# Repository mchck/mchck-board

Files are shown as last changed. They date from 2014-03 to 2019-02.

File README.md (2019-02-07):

The MC HCK!
===========

The goal is to have a small, cheap, and powerful development board
that supports USB for easy programming, at a low price (current
estimate: $7, target $5). This allows us to use the board for all
silly purposes where spending >$20 for other microcontroller boards is
just too much.

The schematic design and layout was done using KiCad <http://kicad.sourceforge.net>,
a Free Software EDA tool for Linux, Windows and Mac OS.  You will need
KiCad to open the .sch or .brd files - gEDA or Eagle will not work.

Copyright
---------

Copyright (c) 2011,2012 Simon Schubert <2@0x2c.org>

This documentation describes Open Hardware and is licensed under the
CERN OHL v. 1.1.  You may redistribute and modify this documentation
under the terms of the CERN OHL v.1.1.  You can find a copy of the
CERN OHL v.1.1 in the file <LICENSE>.

Fabrication outputs
-------------------

If you got this from the git repository, you should be able to find
fabrication outputs in the "fab" branch.  This branch gets updated by
running `make ci-fab`.

Contact
-------

Simon Schubert <2@0x2c.org>

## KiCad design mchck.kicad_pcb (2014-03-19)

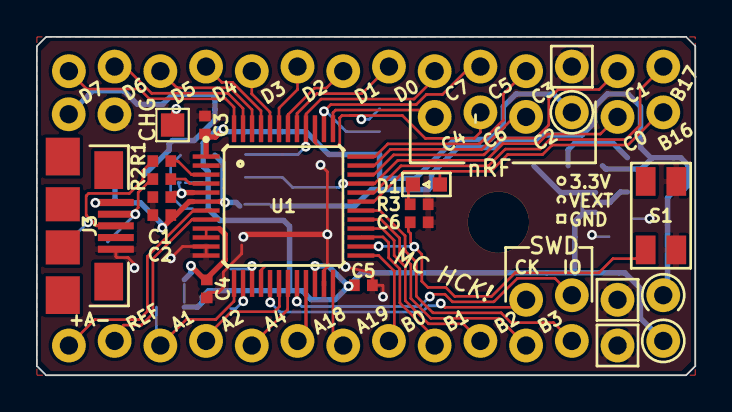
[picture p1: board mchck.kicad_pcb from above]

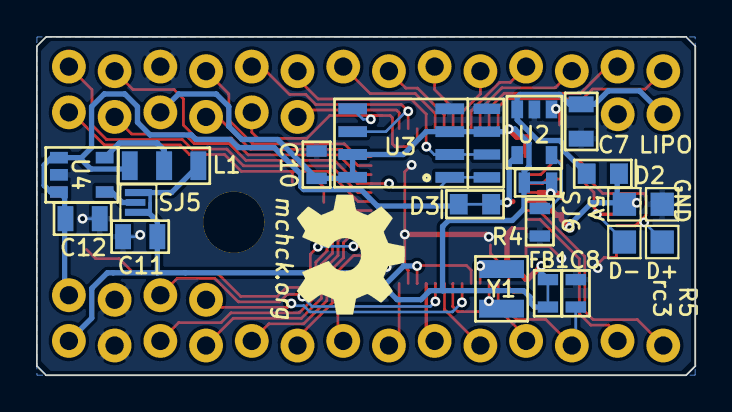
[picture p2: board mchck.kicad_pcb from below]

Board: 2 copper layers, 36.6 x 18.8 mm, 41 parts (26 on the bottom side), 51 nets.

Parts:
C1, C2: 2.2u; SMD-1005
C3, C4, C5, C6: 100n; SMD-1005
C7: 4.7u; SM0805
C8, C10: 100n; SM0603_Capa
C11, C12: 10u; SM0805
D1: LED; LED-0603
D2: CDBU0530; SOD-523F
D3: CDBU0530; SOD-523F-NC
FB1: FILTER; SM0603_NC
G1: OHW LOGO; OHW-LOGO-6mm
H1: MOUNTHOLE; mounthole_3mm
J3: MICRO_USB; SparkFun-USB-MICROB
L1: INDUCTOR_SELECT; SM0805-3WAY
P1: RIGHT_PINS; SparkFun-1X06_LOCK
P2: DEBUG; SparkFun-1X04_LOCK
P3: UPPER_PINS; SparkFun-1X14_LOCK
P4: LOWER_PINS; SparkFun-1X14_LOCK
P5: CHG; solderpad
P7: LIPO; SIL100-2
P9: 5V; solderpad
P10: GND; solderpad
P11: D-; solderpad
P12: D+; solderpad
R1, R2: 33; SMD-1005
R3: 1k; SMD-1005
R4: 20k; SM0603
S1: TAC_SWITCHSMD_EVQP2; TACT_4x3
SJ5: SOLDERJUMPERNO; solder-jumper
SJ6: SOLDERJUMPERNC; SM0603_NC
U1: MK20LF; LQFP48
U2: MCP73831-SOT; SOT23-5
U3: SPI_FLASH-X25XXSMD; SparkFun-SO08
U4: MULTIREG; SOT23-5
Y1: CRYSTAL32-SMD; SparkFun-CRYSTAL-32KHZ-SMD

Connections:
/MCU/+5V: C2.1, D2.C, D3.A, J3.1, P9.1, U1.6, U2.4
/MCU/PL1: P4.1, U1.7
/MCU/PL2: P4.2, U1.8
/MCU/PL3: C8.1, P4.3, U1.13
/MCU/PL4: P4.4, U1.18
/MCU/PL5: P4.5, U1.19
/MCU/PL6: P4.6, U1.21
/MCU/PL7: P4.7, U1.24
/MCU/PL8: P4.8, U1.25
/MCU/PL9: P4.9, U1.27
/MCU/PL10: P4.10, U1.28
/MCU/PL11: P4.11, U1.29
/MCU/PL12: P4.12, U1.30
/MCU/PR1: P1.1, U1.37
/MCU/PR2: P1.2, U1.39, U3.5
/MCU/PR3: P1.3, U1.35
/MCU/PR5: P1.5, U1.33, U3.1
/MCU/PR6: D1.1, P1.6, U1.31
/MCU/PU1: P3.1, U1.48
/MCU/PU2: P3.2, U1.47
/MCU/PU3: P3.3, U1.46
/MCU/PU4: P3.4, U1.45
/MCU/PU5: P3.5, U1.44
/MCU/PU6: P3.6, U1.43
/MCU/PU7: P3.7, U1.42
/MCU/PU8: P3.8, U1.41
/MCU/PU9: P3.9, U1.40, U3.2
/MCU/PU10: P3.10, U1.38, U3.6
/MCU/PU11: P3.11, U1.36
/MCU/PU13: P3.13, U1.34
/MCU/PU14: P3.14, U1.32
/MCU/SWD_CLK: P2.1, U1.17
/MCU/SWD_DIO: P2.2, U1.20
/MCU/USB_DM: R2.2, U1.4
/MCU/USB_DP: R1.2, U1.3
/MCU/VREGUSB: C1.1, SJ6.1, U1.5
/USB/USB_D+: J3.3, P12.1, R1.1
/USB/USB_D-: J3.2, P11.1, R2.1
/power/VLIPO: C7.1, D2.A, P7.1, U2.3
/power/VRAW: C12.1, D3.C, L1.1, P2.4, U4.1, U4.3
unnamed: P5.1, U2.1
unnamed: R4.1, U2.5
unnamed: SJ5.2, U4.4
unnamed: L1.2, U4.5
unnamed: U1.14, Y1.X1
unnamed: C6.1, S1.1, U1.26
unnamed: D1.2, R3.1
unnamed: U1.15, Y1.X2
VDD: C3.1, C5.1, C10.1, C11.1, FB1.1, L1.3, P1.4, P4.14, SJ5.1, SJ6.2, U1.1, U1.16, U1.22, U3.3, U3.7, U3.8
VDDA: C4.1, FB1.2, U1.9, U1.10
VSS: C1.2, C2.2, C3.2, C4.2, C5.2, C6.2, C7.2, C8.2, C10.2, C11.2, C12.2, H1.1, J3.5, P2.3, P3.12, P4.13, P7.2, P10.1, R3.2, R4.2, S1.2, S1.4, U1.2, U1.11, U1.12, U1.23, U2.2, U3.4, U4.2

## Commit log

2011-12-31 move schematics to separate directory
2012-01-07 add SparkFun footprint lib
    Noticed-by: ftoad
2012-02-05 start R2 of mchck (STM32L1 based)
    [charger.sch, mchck.sch, power.sch]
2012-02-05 label pins nicely
    [mchck.sch, power.sch]
2012-02-19 route all pins for R2
    [mchck.brd, mchck.sch, power.sch]
2012-02-19 fix zone pour over default pad connections
    [mchck.brd]
2012-02-19 .gitignore: add more gerber names
2012-02-19 SPI FLASH needs signals at Vdd, not floating
    [mchck.sch]
2012-02-19 fix bad pads, add SPI fixes
    [mchck.brd]
2012-02-22 optimize VEXT routing
    [mchck.brd, mchck.sch, power.sch]
2012-02-22 add mask to solderjumper
    [mchck.brd]
2012-02-22 clean up silk screen
    [mchck.brd]
2012-02-22 silkscreen workout
    [mchck.brd]
2012-02-23 italicize LIPO
    [mchck.brd]
2012-02-23 add board compositing
2012-02-24 tweak composite board colors somehow
2012-02-24 add bypass cap to the SPI flash and clean up silk screen a bit more
    [mchck.brd, mchck.sch, power.sch]
2012-02-24 tweak silkscreen a bit
    [mchck.brd]
2012-02-25 fix diode footprints
    [mchck.brd, mchck.sch, power.sch]
2012-02-25 renumber components, fix ground pours
    [mchck.brd, mchck.sch, power.sch]
2012-02-25 add open logo
    [mchck.brd]
2012-02-25 put composite-board.sh under AGPL3
2012-03-08 implement dual footprint for the flash IC
    [mchck.brd]
2012-05-11 Increase U4 pad Y size to 0.04in
    [mchck.brd]
2012-06-29 Reduce gap of two-way solder jumper
    [mchck.brd]
2012-06-29 Move mini USB connector and add solder jumpers
    Unfortunately the mini USB connector was previously unuseable as it was
    too far from the edge of the board (issue #28). Moreover, when used as
    a standard USB A the housing of a metal female USB A connector would
    short against the pads of the unoccupied mini-USB connector if moved to
    a useable position. For this reason solder jumpers are needed. These
    jumpers will need to be shorted before the mini-USB port can be used.
    [mchck.brd, mchck.sch, power.sch]
2012-08-21 start R3 redesign for NUC120 and aggressive cost push
    [mchck.brd, mchck.sch, power.sch]
2012-08-22 set plot params and sheet comments
    [mchck.brd]
2012-08-22 silkscreen cleanup
    [mchck.brd]
2012-08-27 multi-regulator footprint
    [mchck.brd, mchck.sch, power.sch]
2012-08-28 add logo, fix zones a bit
    [mchck.brd, mchck.sch, power.sch]
2012-08-28 put logo on correct side
    [mchck.brd]
2012-08-28 optimize ground loops
    [mchck.brd]
2012-08-28 more ground loop optimization, add caps for RTC xtal
    [mchck.brd, mchck.sch, power.sch]
2012-08-28 document magical regulator arrangement, beautify silk screen
    [mchck.brd, power.sch]
2012-08-29 makefile: add zip target to collect gerbers
2012-08-29 enlarge SOT23-5 pads, improve micro-USB footprint
    [mchck.brd]
2012-09-04 K20 design
    [mchck.brd, mchck.sch, power.sch]
2012-09-05 clean up schematic
    [mchck.sch, mcu.sch, power.sch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]
2012-09-05 k20 layout (unfinished)
    [mchck.brd, mchck.sch, mcu.sch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]
2012-09-06 K20 layout complete
    [mchck.brd, mchck.sch, mcu.sch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]
2012-09-06 fix odd file format
    [usb.sch]
2012-09-06 renumber refs based on location
    [mchck.brd, mchck.sch, mcu.sch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]
2012-09-06 don't route under no-mask area
    [mchck.brd]
2012-09-07 add M3 mounting hole
    [mchck.brd, mchck.sch, mcu.sch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]
2012-09-07 add silkscreen markings for power
    [mchck.brd]
2012-09-08 silkscreen work
    [mchck.brd, mchck.sch, mcu.sch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]
2012-09-08 rearrange swd pins, finish up silkscreen
    [mchck.brd, mchck.sch, mcu.sch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]
2012-09-08 move OHW logo a bit
    [mchck.brd]
2012-09-09 enlarge double inductor footprint to take 2016(metric) L
    [mchck.brd]
2012-09-09 add zones for regulator
    [mchck.brd]
2012-09-10 better ground plane routing
    [mchck.brd]
2012-09-11 replace BATT SJ with diode footprint
    [mchck.brd, mchck.sch, mcu.sch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]
2012-09-22 make micro-usb 5V track thicker
    [mchck.brd]
2013-01-02 External xtal pads added, USB OTG connectivity
    Additions:
    - added 3.2 mm x 2.5 mm xtal pads on the back, connected with PL6/PL7
    - reduced OHW logo size to 3 mm
    - added optional connectivity from the USB OTG pin through PL1
    Other minor fixes:
    - fixed some minor connectivity issue showing in DRC due to Kicad bugs
    - fix board to allow requirements to allow submission to OSH Park:
    increase via sizes to 23 mils minimum, increase copper interval to board
    edges to 15 mil
    [mchck.brd, mchck.sch, mcu.sch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]
2013-05-18 Revert "External xtal pads added, USB OTG connectivity"
    This reverts commit 6c898d9e8dd50c32c7d8a56c6982c2bd0973ab0d.
    The schematic and layout changes were too intrusive for now. Better
    cook this a bit longer before pulling it into main.
    [mchck.brd, mchck.sch, mcu.sch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]
2013-07-24 schematic: mark components as optional, rearrange power routing
    [mchck.sch, mcu.sch, power.sch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]
2013-07-27 r5 layout
    [mchck.brd, mchck.sch, mcu.sch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]
2013-07-27 Makefile: adapt to kicad file name changes
2013-07-28 move user-accesible capacitor outside
    [mchck.brd]
2013-07-28 use non-SJ footprints
    [mchck.brd]
2013-07-28 chamfer board outline
    [mchck.brd]
2013-07-28 Makefile: flip composite board again
2013-07-31 schematic: don't use identifiers in comment
    They just change under us and become stale.
    [power.sch]
2013-07-31 Makefile: kicad schematic plots changed name
2013-08-03 use proper field marker for optional parts
    [power.sch]
2013-08-03 Makefile: add target to print BOM
2013-08-06 slight reroute
    [mchck.brd]
2013-08-13 allow USB/battery split power
    [mchck.brd, mchck.sch, mcu.sch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]
2013-08-13 set proper gerber plotting arguments
    [mchck.brd]
2013-08-15 set soldermask clearances to 0.1mm
    [mchck.brd]
2013-08-29 fix lost USB component
    [mcu.sch, power.sch, usb.sch]
2013-08-29 rearrange SWD connector
    [mchck.brd, mchck.sch, mcu.sch]
2013-08-29 this is rc3 now
    [mchck.brd, mchck.sch, mcu.sch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]
2013-08-29 shorten USB tab
    [mchck.brd]
2013-08-29 fix silkscreen
    [mchck.brd]
2013-08-29 drop ground ferrite + clean up some routing
    [mchck.brd, power.sch]
2014-02-28 drop usb tab
    [mchck.brd, mchck.sch, mcu.sch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]
2014-02-28 use 100 mil instead of jst 1.5
    [mchck.brd, mchck.sch, mcu.sch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]
2014-03-19 zone cutouts, silkscreen fixes, new board file format
    [mchck.brd, mchck.kicad_pcb]
2014-03-19 properly mark R5 rc3 on silk screen
    [mchck.kicad_pcb]
2014-03-19 gerbers are now called *.pho

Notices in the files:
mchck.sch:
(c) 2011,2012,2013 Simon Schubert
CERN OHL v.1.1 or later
